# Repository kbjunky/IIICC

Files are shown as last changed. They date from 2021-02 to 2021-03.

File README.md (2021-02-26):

# IIICC
### Three piece split keyboard with macropad running QMK
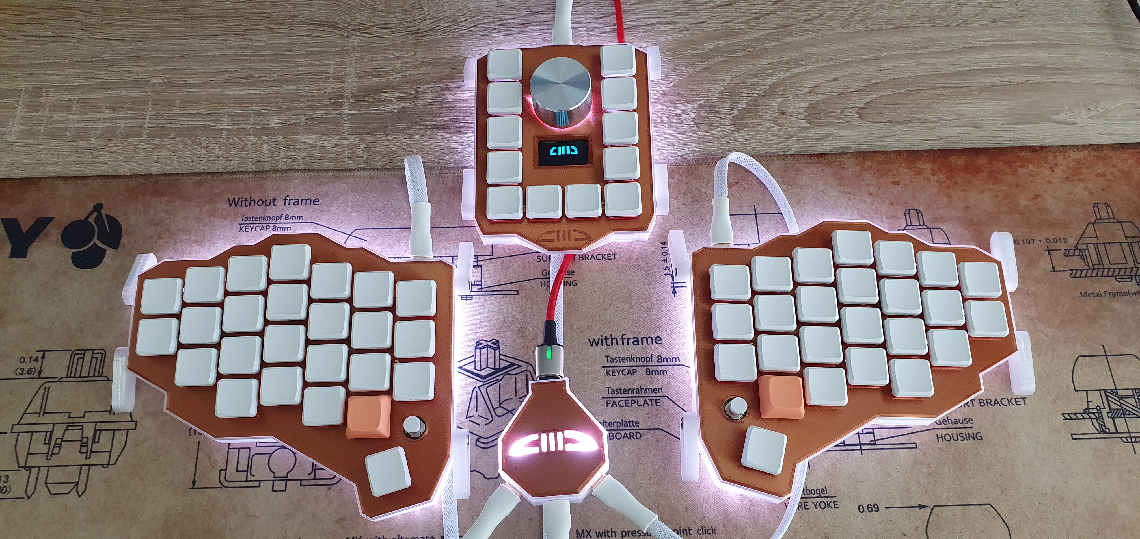
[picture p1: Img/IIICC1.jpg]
IIIC1

Features
- Split ergo
- Additional optional macropad with OLED and rotary encoder
- Central Hub design with only one controller to flash
- 5 way switch on each half for additonal functionality 
- Support for tenting (Ergodox feet should fit), rubber/aluminum feet, 3D printed (included)
- RGB underglow
- 3D printed case and plates
- Support for Kailh Choc V1, Choc V2 and X-Switch(laptop scissor) 
- QMK firmware
- All USB-C connectors
- 'Hexa' case designed by [Sean Yin](https://www.coroflot.com/sean_yin)

[Assembly manual](Doc/IIICC_Assembly_Guide.pdf)

[IIICC PCB & Ordering @ EasyEDA](https://easyeda.com/pigboard)

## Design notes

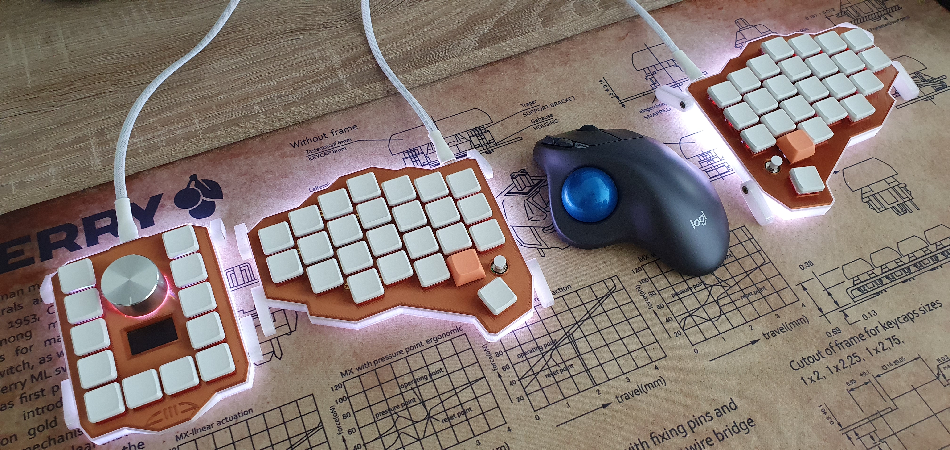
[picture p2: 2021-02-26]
Img/IIICC2.jpg

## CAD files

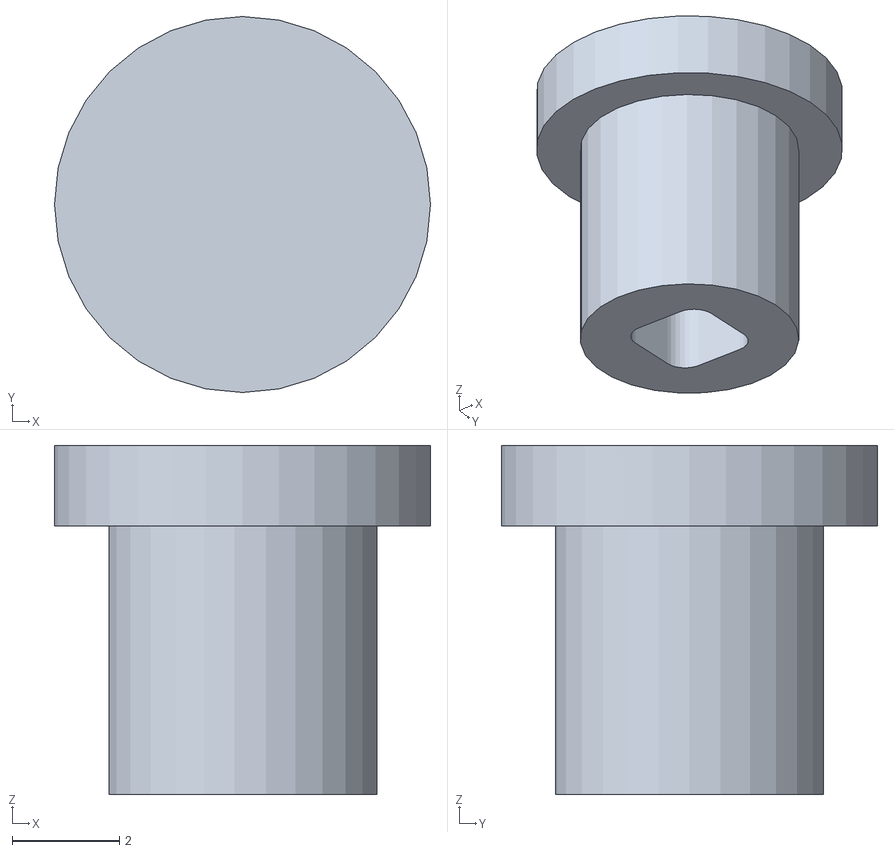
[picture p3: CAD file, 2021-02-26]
Case/3DP/5W_Switch_Cap/5WSwitchCap.stl
7.00 x 7.00 x 6.50

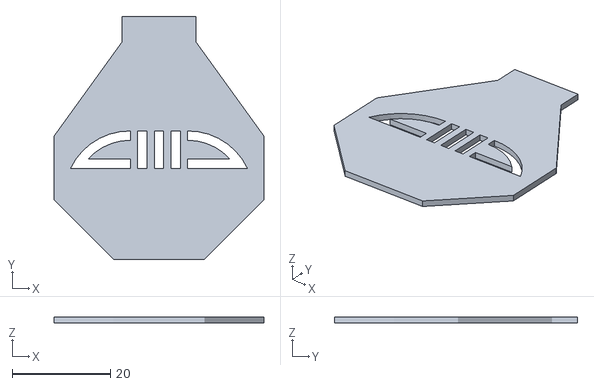
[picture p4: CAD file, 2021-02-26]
Case/3DP/Hub/Hub-Lid_Top.stl
42.6 x 49.4 x 1.20

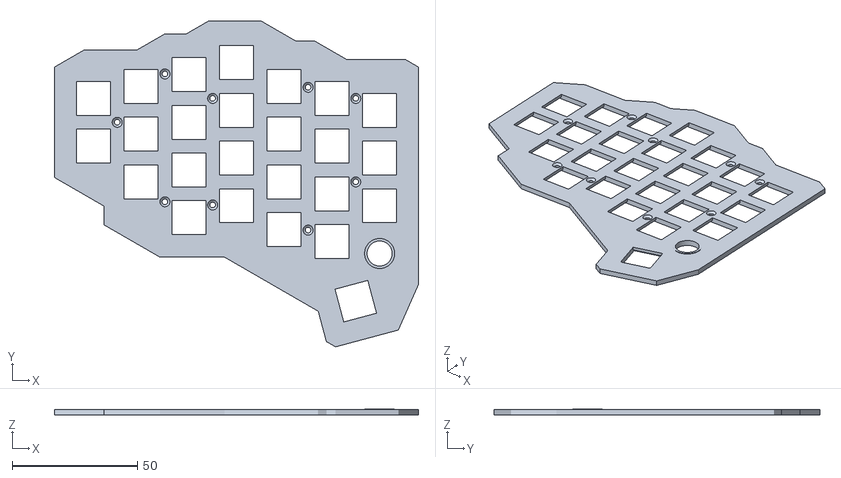
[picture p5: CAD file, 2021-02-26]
Case/3DP/Keyboard/IIICC-Top_Plate_Choc_V1V2.stl
145.3 x 130.1 x 2.40

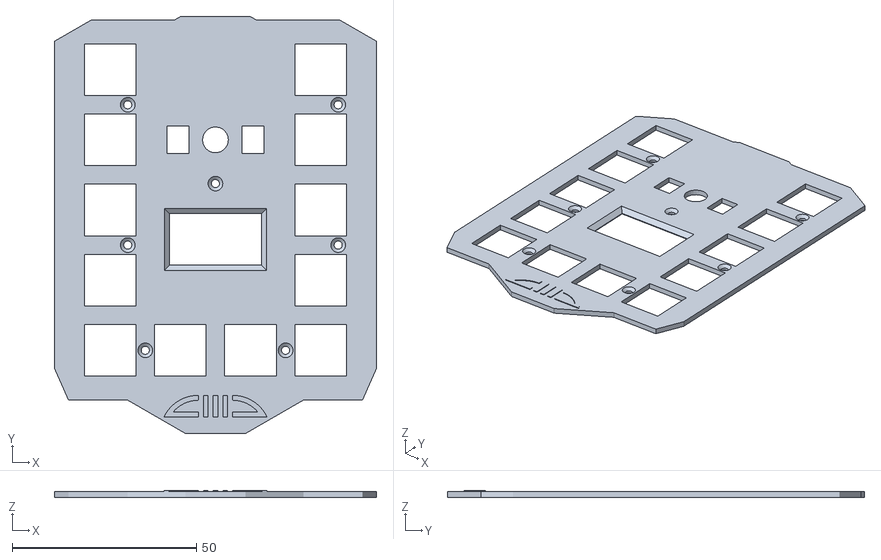
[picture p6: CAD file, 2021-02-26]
Case/3DP/Macropad/Macropad-Top_XSwitch.stl
87.6 x 113.2 x 1.80

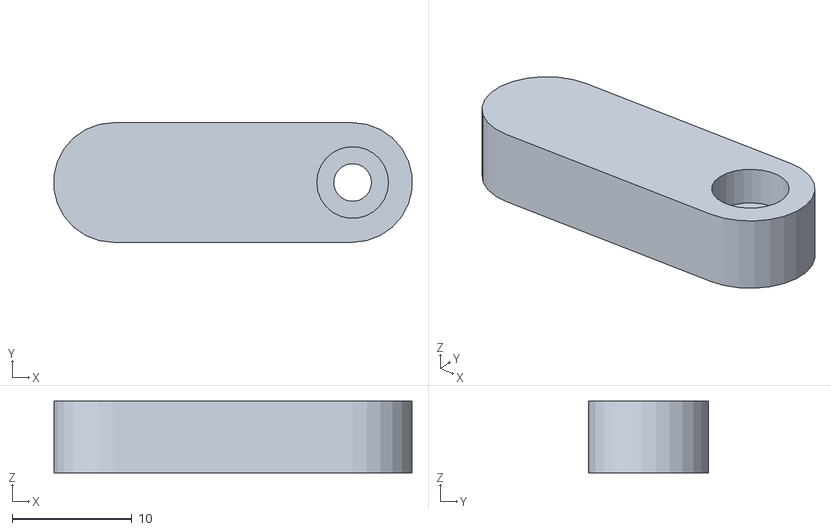
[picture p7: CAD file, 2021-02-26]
Case/3DP/Tenting_Feet/Feet-20mm.stl
29.9 x 10.0 x 6.00

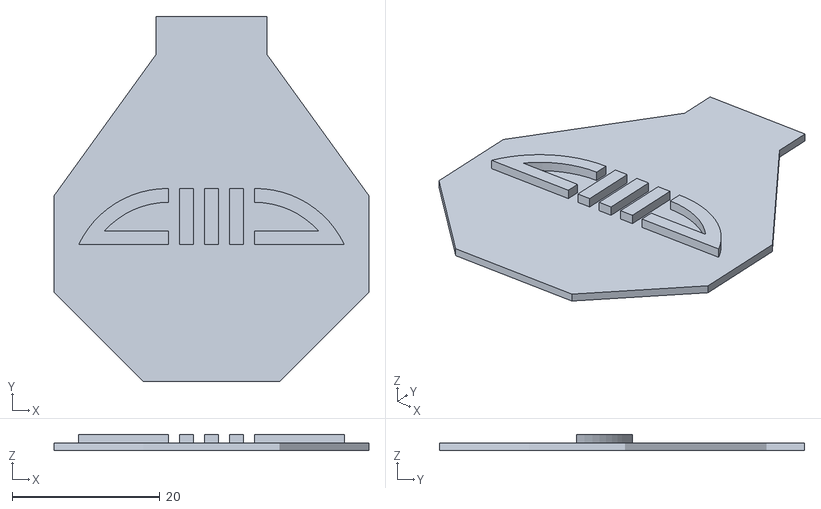
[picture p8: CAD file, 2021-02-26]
Case/3DP/Hub/Hub-Lid_Bottom.stl
42.6 x 49.4 x 2.20

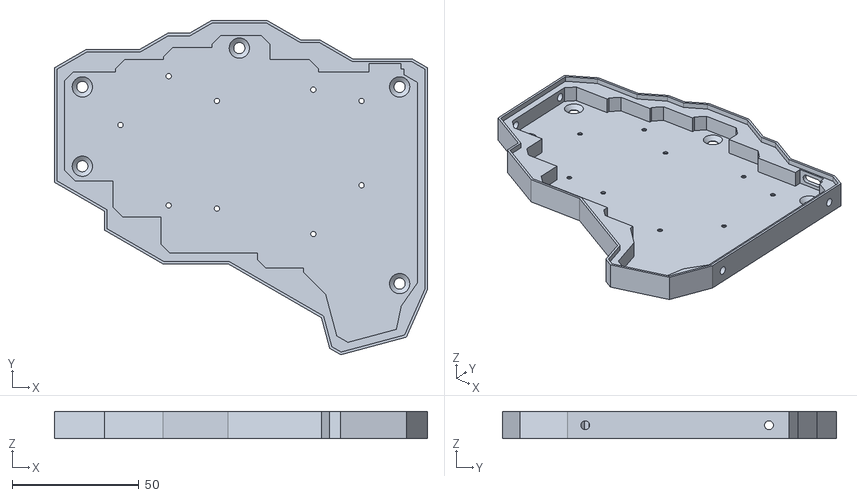
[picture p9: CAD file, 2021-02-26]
Case/3DP/Keyboard/IIICC-Bottom.stl
147.4 x 132.1 x 10.8

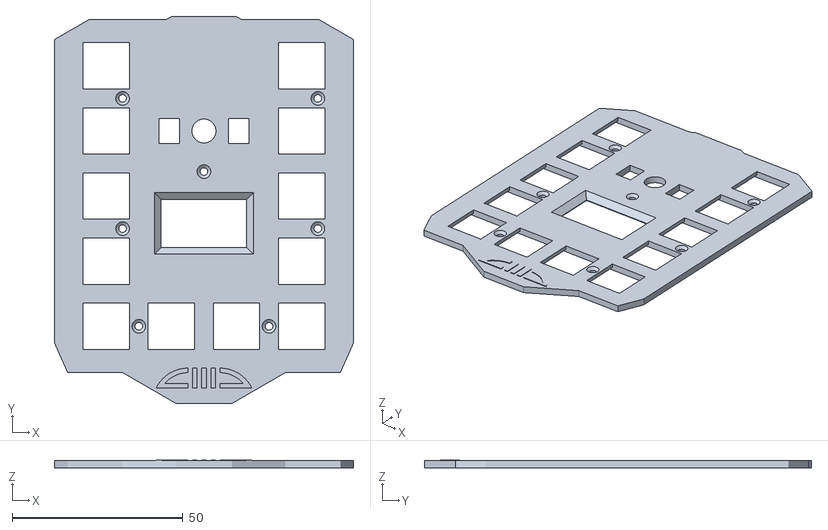
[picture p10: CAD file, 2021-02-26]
Case/3DP/Macropad/Macropad-Top_Plate_ChocV1V2.stl
87.6 x 113.2 x 2.40

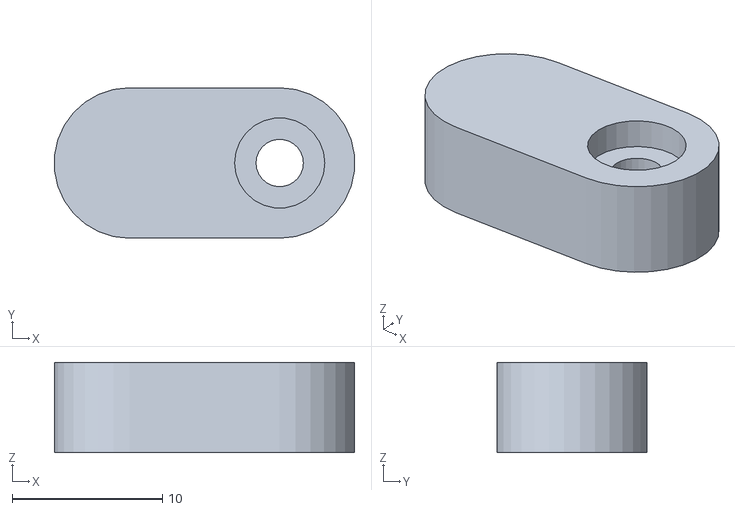
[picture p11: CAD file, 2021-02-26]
Case/3DP/Tenting_Feet/Feet-10mm.stl
19.9 x 10.0 x 6.00

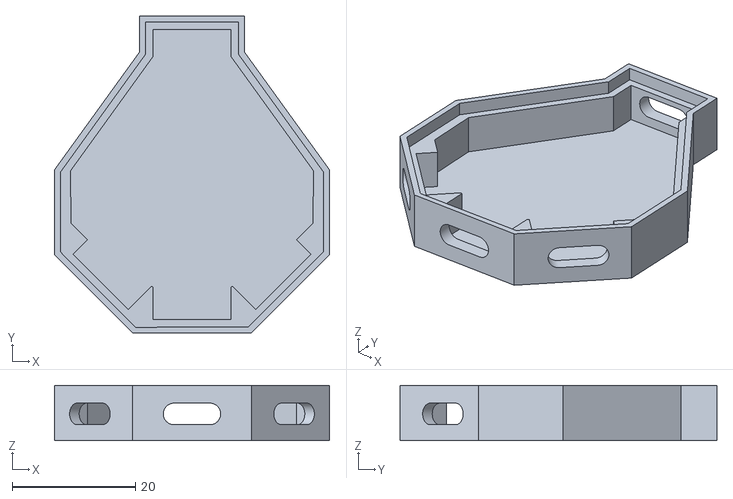
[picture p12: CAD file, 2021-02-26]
Case/3DP/Hub/Hub-Bottom.stl
44.6 x 51.4 x 9.00

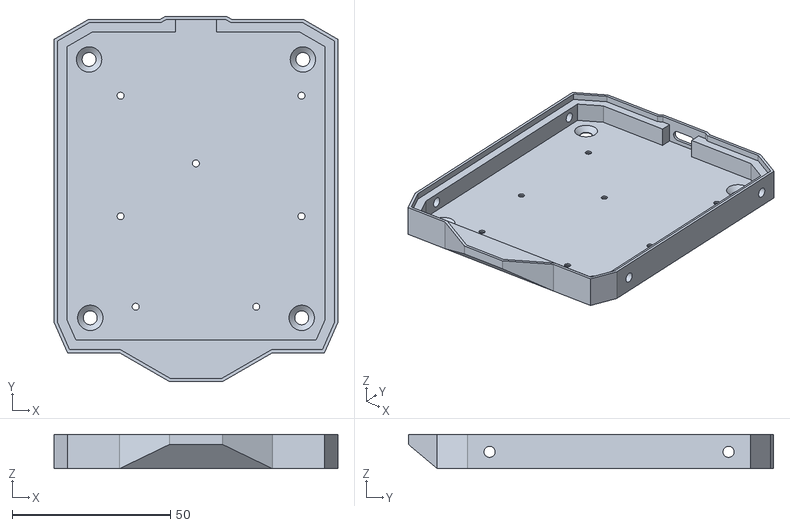
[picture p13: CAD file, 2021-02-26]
Case/3DP/Macropad/Macropad-Bottom.stl
89.7 x 115.3 x 10.8

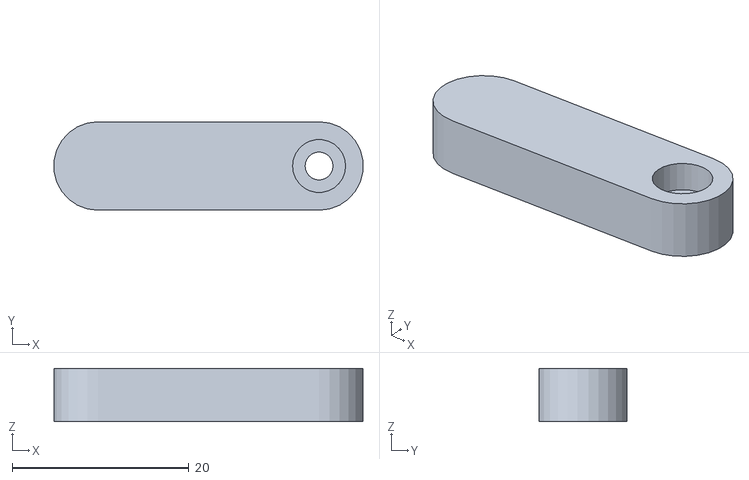
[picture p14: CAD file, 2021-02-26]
Case/3DP/Tenting_Feet/Feet-25mm.stl
34.9 x 10.0 x 6.00

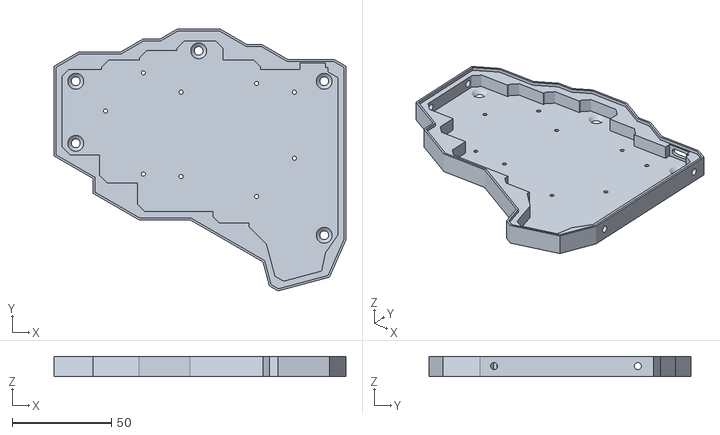
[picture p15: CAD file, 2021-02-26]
Case/3DP/Keyboard/IIICC-Bottom_XSwitch.stl
147.4 x 132.1 x 10.2

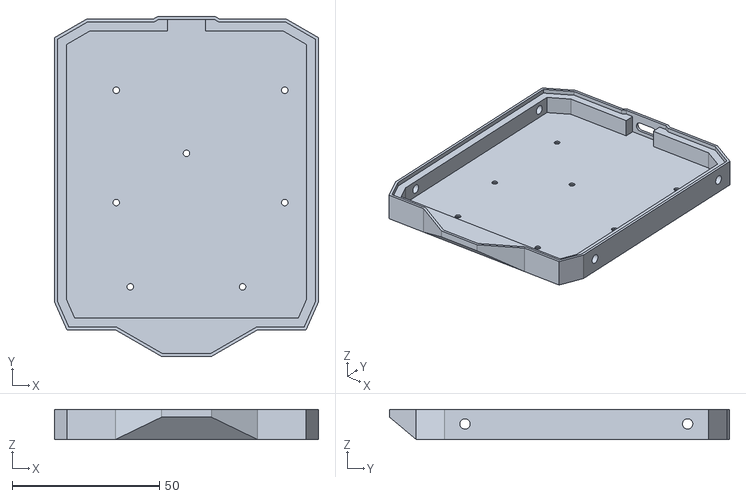
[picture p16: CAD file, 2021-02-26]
Case/3DP/Macropad/Macropad-Bottom_No_Feet_XSwitch.stl
89.7 x 115.3 x 10.2

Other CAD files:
Case/3DP/Keyboard/IIICC-Bottom_No_Feet.stl
Case/3DP/Keyboard/IIICC-Bottom_No_Feet_XSwitch.stl
Case/3DP/Macropad/Macropad-Bottom_XSwitch.stl
Case/3DP/Keyboard/IIICC-Top_XSwitch.stl
Case/3DP/Macropad/Macropad-Bottom_No_Feet.stl

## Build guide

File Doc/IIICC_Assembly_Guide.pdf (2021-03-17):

IIICC by kbjunky (https://www.reddit.com/user/kbjunky) & Sean Yin (https://www.coroflot.com/sean_yin)

### 3 piece split keyboard

Assembly Guide

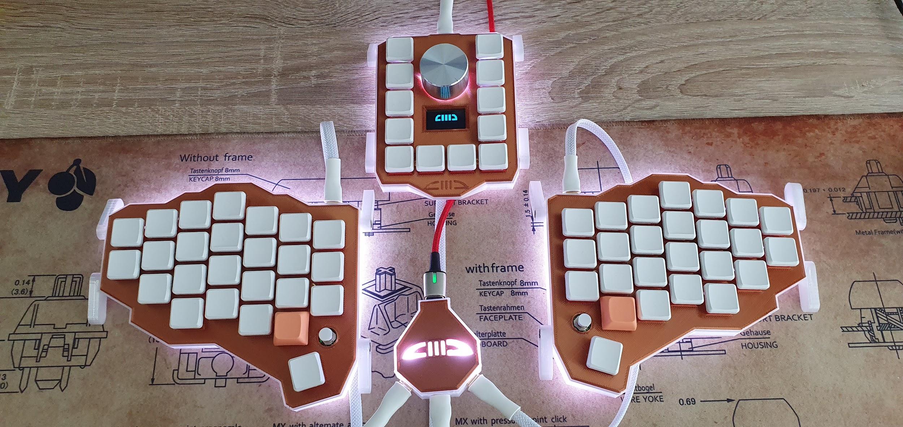
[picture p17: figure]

Bill of materials
Item | Size | Count
22 Ohm | R0805 | 2
330 Ohm | R0805 | 1
1.5k Ohm | R0805 | 1
100nF | C0805 | 51
10k Ohm | R0805 | 2
10uF | C0805 | 1
Oscillator 16MHz | OSC-SMD_4P-L3.2-W2.5-BL | 1
1k Ohm | R0805 | 3
1N4148W T4 | SOD-123_L2.8-W1.8-LS3.7-R D | 75
1uF | C0805 | 1
22pF | C0805 | 2
3.3k Ohm | R0805 | 1
4.7k Ohm | R0805 | 3
4.7uF | C0805 | 1
5.1k Ohm | R0805 | 2
Atmega32U4-AU | QFP-44_L10.0-W10.0-P0.80-LS13.2-BL | 1
USB-C (https://www.aliexpress.com/item/4000259156096.html?spm=a2g0s.9042311.0.0.27424c4d5Fyja3) | | 7
MCP23018-E/SS | SSOP-24_L8.1-W5.3-P0.65-L S7.8-BL | 3
Encoder (https://sg.rs-online.com/web/p/mechanical-rotary-encoders/7377742/) | SW-TH_PEC11R-4220F-S001 2 | 1
Reset button | SW-SMD_L4.0-W2.9-LS5.0 | 1
5W Switch | SW-SMD_TSW-10-1-11B-T15 | 2
WS2812B-B | | 44
OLED 128x64 | | 1
Kailh Choc Hot Swap Socket (https://www.aliexpress.com/item/33023283633.html?spm=2114.12010612.8148356.47.2c2c7aebR0yRfH) | | 50/62
Switches Choc V1/V2/X-Switch | | 50/62
Keycaps | | 50/62
M2 brass flat head screw (https://www.aliexpress.com/item/32792555301.html?spm=a2g0s.9042311.0.0.27424c4dklPrzY) | 6mm | 25
M2 brass flat head screw | 3mm | 25
M2 brass heat insert (https://www.aliexpress.com/item/33021847966.html?spm=a2g0s.9042311.0.0.27424c4dKZ5yBq) | 5mm | 25
M3 hex socket screw (https://www.aliexpress.com/item/4000142028043.html?spm=2114.12010612.8148356.3.2ffa4f9avSfkV5) | 8mm | 12
M3 Thumb screw (https://www.aliexpress.com/item/4000838593040.html?spm=a2g0s.9042311.0.0.27424c4dJjg4a6) | 8mm | 12
Adhesive rubber feet (https://www.aliexpress.com/item/32514500567.html?spm=2114.12010615.8148356.3.3b54498dIeNpzB) | 8x2mm | 20
Double sided adhesive tape (https://www.aliexpress.com/item/4000112107339.html?spm=a2g0s.9042311.0.0.27424c4dF2PZZv)
Aluminum Feet (https://www.aliexpress.com/item/4000643228244.html?spm=a2g0s.9042311.0.0.27424c4de4gp5l) | | 14
Interconnect USB-C Cable (https://www.aliexpress.com/item/4001186462883.html?spm=2114.12010615.8148356.1.729f43ebnEV6Sc) | 0.5m | 3
Magnetic USB-C Hub<->PC Cable (https://www.aliexpress.com/item/4000587078878.html?spm=2114.12010615.8148356.1.9898166ckRijmm) | | 1
Encoder Knob (https://www.aliexpress.com/item/4000317755965.html?spm=a2g0s.9042311.0.0.27424c4dtww8v0) | 30x17mm | 1

About keycap compatibility

All Choc V1 caps should fit including MBK. Good idea is to put XDA on Space and Enter while using Choc V1. This gives a bit more flexibility while pressing those keys (easier to reach with a thumb).

For Choc V2 I have tested only two types:
YMDK XDA (https://www.aliexpress.com/item/32864098498.html?spm=a2g0s.9042311.0.0.27424c4dmsWMkX) - OK

YMDK ABS OEM(?) profile (https://www.aliexpress.com/item/32834702181.html?spm=a2g0s.9042311.0.0.27424c4djNetZY) - for this only buy R1 to R3 and use reversed R1 on row 4 (bottom row). R4 keycaps from this store won’t hold, seems like they are too high (more like switch/stem being too short).
In terms of keycaps hitting the plate on Choc V2 I have not noticed any problem with that. Seems like there’s still tiny space left.

For Kailh X-Switch there are no other keycaps than the one Kailh is selling on their store. Link. (https://www.aliexpress.com/item/32987116768.html?spm=2114.12010612.8148356.23.100836a4Enr8On)

About LEDs and USB-C

I have made available pads for VCC/GND/D+/D-/LED_DATA on the PCB. A USB-C pinout board can be used but most probably it won’t fit the case. Maybe in the future I will add a slightly angled case so this might come handy. As for LEDs a WS2812 strip can be used instead of soldering all the capacitors and LEDs.

PCB Ordering

PCBs were created using EasyEDA and can be directly ordered from there. Use default settings when making your order, that is:
Layers: 2
PCB Qty: 5 (min) or more depending on your needs
Delivery format: Single PCB
PCB Thickness: 1.6mm
PCB Color: Green (default) but you can choose any other color available Surface Finish: HASL(with lead)
Copper Weight: 1 oz
Gold fingers: No
Confirm production file: No Flying probe Test: Fully Test
Castellated Holes: No
Remove Order Number: No

Each part has to be ordered separately. Left, Right and Hub are mandatory. Macropad is optional.

Tools

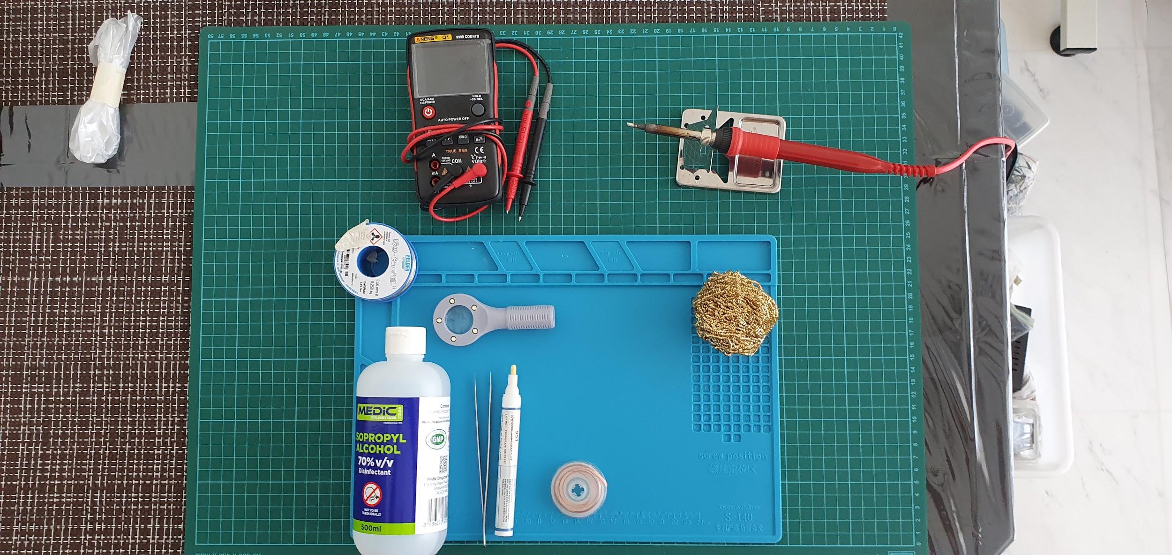
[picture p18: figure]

Minimum set of tools/materials required for this build: Soldering iron. (https://www.aliexpress.com/item/1005001343006528.html)
0.5mm Lead Solder. (https://sg.rs-online.com/web/p/solder/1796656/)
No clean flux. Marker (https://www.aliexpress.com/item/33004145488.html) or syringe. (https://www.aliexpress.com/item/32788246494.html)
Multimeter (https://www.aliexpress.com/item/1005001693526242.html) with diode test.
Tweezers (https://www.aliexpress.com/item/32819516775.html) for SMD elements.
Isopropyl alcohol for cleaning PCBs. (Got mine at a pharmacy store)
Magnifying (https://www.aliexpress.com/item/4001275940469.html) glass might come handy especially if it’s on an arm. Or anything to help with soldering USB-C ports and ICs.
Hot glue gun (https://www.aliexpress.com/item/1005001393578323.html) to secure USB-C ports to the PCB
Desoldering wick (https://www.aliexpress.com/item/32958719300.html) for cleaning of solder when things go wrong.
Brass sponge (https://www.aliexpress.com/item/32964436795.html) for cleaning the tip.

Assembly

You should start with the Hub. First solder in USB-C port that connects Hub to the PC. Check for shorts using pads on the PCB.
D+ <-> D-GND <-> Vcc
VCC <-> CC1 (5.1k resistor pad)
D- <-> CC2 (5.1k resistor pad)

Next solder in the rest of USB ports one at a time checking for shorts on: VCC <-> RGB
VCC <-> GND
SDA <-> SCL
SCL <-> RGB

After this is done you can proceed to installing Atmega and all the elements around it. For now skip LED diodes and 100nF capacitors located between them and the edge of the board. Once done connect the board to the PC. If you see a message about an unrecognized device most probably there’s a short on VCC and or D+/D-. Double check with a multimeter. If all is good you should be able to flash firmware onto it. Follow QMK guide on flashing firmware.
Finish assembly by installing LEDs and accompanying capacitors. Connect again to check if LEDs are working fine. Be sure to have Macropad disabled for the testing phase as without an OLED screen present driver might freeze the controller.

Next assemble either the left or right keyboard part. Leave the macropad last. Steps below apply to all of the parts.
Just like with the Hub first thing that needs to be installed is the USB-C port. Check for shorts using pads on the PCB.
SCL <-> SDA
RGB <-> SCL
Vcc <-> RGB
Vcc <-> GND

After that install I2C expander (MCP23018) and: Right:
4.7k address resistor
1k Reset pull-up resistor
100nF Vcc capacitor

Left:
1k Reset pull-up resistor
100nF Vcc capacitor

Macropad:
1.5k and 3.3k address resistors 1k Reset pull-up resistor
100nF Vcc capacitor

After MCP23018 is installed you should check for shorts on:
Vcc <-> SCL
SCL <-> SDA

At this point it’s good to check if communication is working. Install one diode to the nearest switch to the USB-C port. Connect this part to the Hub and use https://keycode.info/ to check if keypress is reported. If not check again for any shorts on the I2C line as well as Vcc/GND. If it works the rest is easy but a bit time consuming. Install all switching diodes, check each key if it works. Then you can proceed to LEDs + capacitors. Best way to install LEDs is in small steps. One or two diodes at a time and check if they work. After that install hot swap sockets. Last but not least, the 5W switch. It doesn’t like high temperatures for too long as well as too much solder. Install it as the last element and don’t use too much solder/heat. Otherwise it might stop being ‘tactile’.

Special note on macropad.
Two things require special steps: an OLED screen and a rotary encoder. OLED should fit inside the cutout. Place it there and use hot glue to glue it to the pcb. Then use a wire to connect OLED to the VCC, GND, SDA, SCL pads nearby.

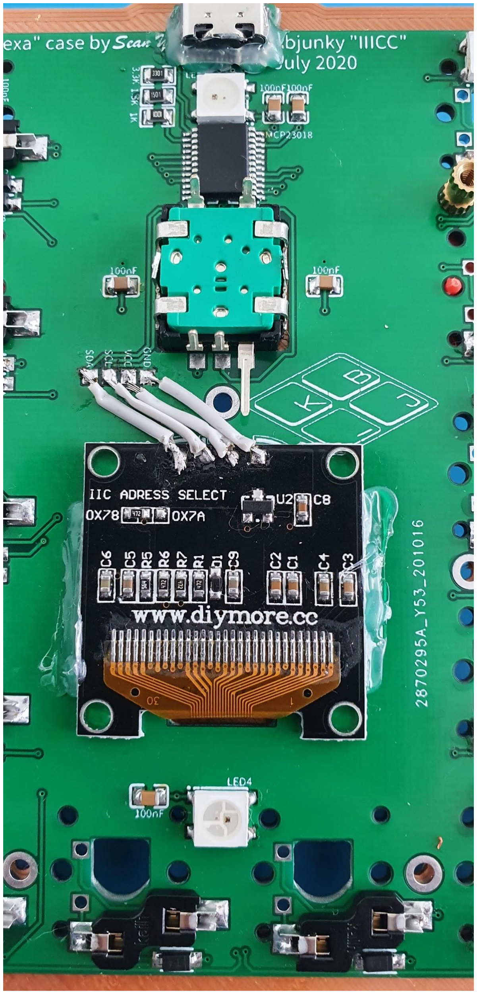
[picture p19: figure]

If your OLED doesn’t work you can try changing its address in firmware. Oddly enough the one I have used while building had the same address as 128x32 which is 3C. 128x64 usually has an address of 0x7C or 0x78 (it’s at the back of the screen).

As for the encoder it’s best to have the top plate printed. Push it through the hole in the plate and tighten with the screw. Now attach the plate to the PCB so that it won't be moving (2 screws will do). Cut off the GND pins (the thick ones on the sides) we won’t be needing them. Position the rotary encoder so that pins align with pads on the pcb (3 bottom ones and 2 on top). Now bend the pins towards the PCB and trim them so that they are touching the PCB. Solder them to the pads and put the washer and the nut that came with the encoder on the top part of the plate to secure it further.

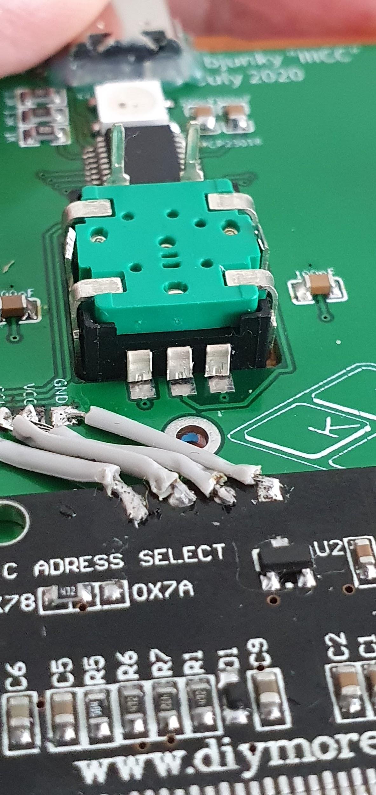
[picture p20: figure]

Case assembly

At this point you should have all the pieces working so it’s a good time to use hot glue on USB-C ports to secure them to the PCB.
Choose Choc V1/V2 or X-Switch compatible parts. It’s possible to print Choc V1/V2 compatible bottom case and use it with an X-Switch plate. Only difference is that the outline of the case will be slightly higher than the plate. It’s because the plate for Choc is 2.2mm and for X-Switch 1.6. Also decide if you need support for bottom rubber feet or not (additional M4 holes on the bottom). After printing is done assembly is rather easy. Install heated inserts on the sides. Attach PCB to the top plate with a 6mm flat head screw (from the top). Heated inserts will also be used as spacers on the bottom side of the PCB where the top plate mounting screws are. Once this is done put two pieces together. Top plate should click in. From the bottom screw in 3mm flat head screws to secure top plate and bottom case together.
Hub doesn’t need any screws. All parts should fit in tight. Insert PCB into bottom case. First insert USB-C to PC port. Then slide it back a bit so that all the ports align. Then the top plate is two pieces. Transparent bottom one with extruded IIICC logo should fit with the top one in a way that extruded letters go through IIICC cutout in the top part.

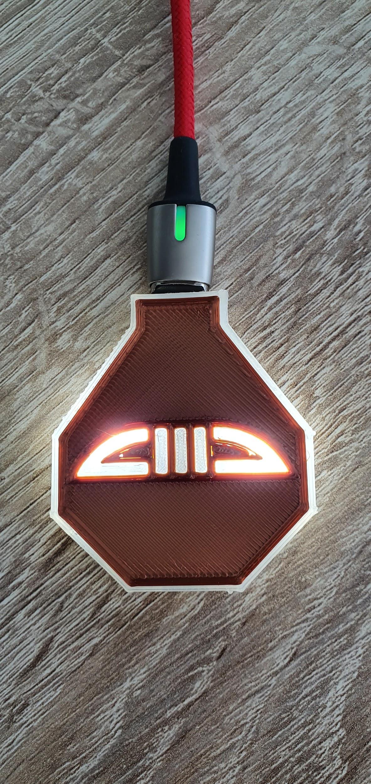
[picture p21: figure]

Tenting feet

You can choose between 25mm, 20mm and 10mm so it’s more of a trial and error before you find the most suitable ones. Use double sided adhesive tape to prevent the keyboard from sliding while tented.

Printing

Top plates printed with shiny copper PLA Layer height 0.2
Infill 100%

Bottom cases printed with translucent PLA
Layer height 0.2
Infill 30%
Support ON (unless your printer can print USB-C cutout without it)

Feet
Layer height 0.2
Infill 30%

5W Switch cap
Layer height 0.2
Infill 100%

Layout

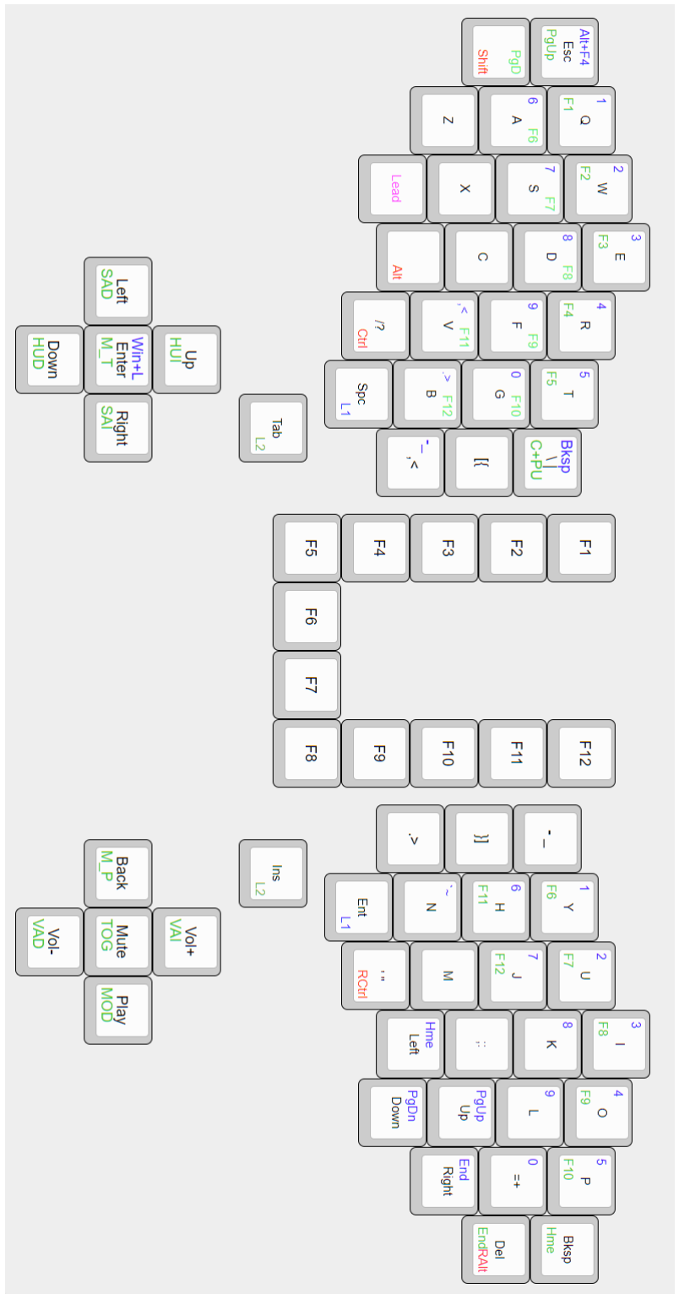
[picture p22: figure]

Leader key combinations:

+ W - Win
+ B - Reset/Programming
+ W,R - Command
+ W,L - Logout
+ W,S - Screenshot
+ W,T - Win+Tab (cycle Windows) + C,A,D - Ctrl+Alt+Del
+ C,A,E - Ctrl+Alt+End (for RDP) + A - Alt+Shift+Insert (Far Manager) + Q - Ctrl+PgUp (Far Manager)
+ S - Caps Lock

Compilation

Prepare your build environment by following QMK official Getting Started (https://docs.qmk.fm/#/newbs_getting_started) guide. Checkout code from my Github repository at https://github.com/kbjunky/IIICC. Default setup will compile with macropad support thus if it’s not present (especially when OLED is not installed) it might cause some problems.

To enable macropad and OLED:
In rules.mk:
OLED_DRIVER_ENABLE = yes
In config.h:
#define MACROPAD_ENABLE

To disable macropad and OLED:
In rules.mk:
OLED_DRIVER_ENABLE = no
In config.h:
//#define MACROPAD_ENABLE

If you are having issues with the keyboard enable debug mode and check output either in QMK Toolbox or hid_listen.exe. Underglow needs to be disabled while console is enabled otherwise firmware will exceed allowed size:
To enable debug mode:
In rules.mk:
CONSOLE_ENABLE = yes
RGBLIGHT_ENABLE = no

You can also enable/disable boot animation and change it’s interval. In keymap.c:
#define BOOT_ANIM_ENABLED

#define BOOT_ANIM_DELAY 125

Hub can support a matrix of 3 devices of 8 columns and 8 rows each. Can be easily extended by modifying IIICC.h with a new key matrix.

Links

https://easyeda.com/pigboard - my electronics projects including IIICC https://github.com/kbjunky/IIICC - IIICC Github page https://www.coroflot.com/sean_yin - designer of ‘Hexa’ case art page kbjunky#6476 - Discord

Enjoy your IIICC
Thank you!

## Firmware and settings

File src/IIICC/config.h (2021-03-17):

/*
Copyright 2020 kbjunky

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
You should have received a copy of the GNU General Public License
along with this program.  If not, see <http://www.gnu.org/licenses/>.
*/

#pragma once

#include "config_common.h"


/* USB Device descriptor parameter */
#define VENDOR_ID 0xFEED
#define PRODUCT_ID 0x0000
#define DEVICE_VER 0x0001
#define MANUFACTURER kbjunky
#define PRODUCT IIICC
#define DESCRIPTION Three Split keyboard with macropad

/* Macropad */
#define MACROPAD_ENABLE //uncomment to enable macropad

/* OLED settings */
//#define OLED_DISPLAY_ADDRESS 0x78 //128x64 sometimes run on 0x3C just like 128x32, that was the case for me
#define OLED_DISPLAY_128X64
#define OLED_FONT_H "keyboards/IIICC/glcdfont.c"
#define OLED_TIMEOUT 0
//full matrix, we skip macropad scanning in matrix.c if not defined here
#define MATRIX_ROWS 5
#define MATRIX_COLS 20

/* COL2ROW, ROW2COL*/
#define DIODE_DIRECTION COL2ROW

/* Debounce reduces chatter (unintended double-presses) - set 0 if debouncing is not needed */
#define DEBOUNCE 10

#define NO_ACTION_MACRO
#define NO_ACTION_FUNCTION

/* Leader key */
#define LEADER_TIMEOUT 450
#define LEADER_PER_KEY_TIMING

/* Tapping timout */
#define TAP_CODE_DELAY 20
#define TAPPING_TERM 200
#define PERMISSIVE_HOLD
#define IGNORE_MOD_TAP_INTERRUPT

/* RGB Light */
#define RGB_DI_PIN F4
#ifdef RGB_DI_PIN
   #define RGBLED_NUM 16
   #define RGBLIGHT_HUE_STEP 10
   #define RGBLIGHT_SAT_STEP 15
   #define RGBLIGHT_VAL_STEP 15
   #define RGBLIGHT_LIMIT_VAL 255 /* The maximum brightness level */
   #define RGBLIGHT_SLEEP  /* If defined, the RGB lighting will be switched off when the host goes to sleep */
 /*== all animations enable ==*/
   #define RGBLIGHT_ANIMATIONS
 /*== or choose animations ==*/
//    #define RGBLIGHT_EFFECT_BREATHING
//    #define RGBLIGHT_EFFECT_RAINBOW_MOOD
//    #define RGBLIGHT_EFFECT_RAINBOW_SWIRL
//    #define RGBLIGHT_EFFECT_SNAKE
//    #define RGBLIGHT_EFFECT_KNIGHT
//    #define RGBLIGHT_EFFECT_CHRISTMAS
//    #define RGBLIGHT_EFFECT_STATIC_GRADIENT
//    #define RGBLIGHT_EFFECT_RGB_TEST
//    #define RGBLIGHT_EFFECT_ALTERNATING
// /*== customize breathing effect ==*/
//   /*==== (DEFAULT) use fixed table instead of exp() and sin() ====*/
//   #define RGBLIGHT_BREATHE_TABLE_SIZE 256      // 256(default) or 128 or 64
//   /*==== use exp() and sin() ====*/
//   #define RGBLIGHT_EFFECT_BREATHE_CENTER 1.85  // 1 to 2.7
//   #define RGBLIGHT_EFFECT_BREATHE_MAX    255   // 0 to 255
 #endif

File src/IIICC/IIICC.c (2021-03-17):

/* Copyright 2020 kbjunky
 *
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
 * You should have received a copy of the GNU General Public License
 * along with this program.  If not, see <http://www.gnu.org/licenses/>.
 */

#include "IIICC.h"

#define HIGH 0b11111111
#define LOW 0

static i2c_status_t last_err = 0;
bool i2c_initialized = false;

void i2c_initialize(void){
    dprint("I2C init start\n");
     
    if(!i2c_initialized) {
        i2c_init();
        i2c_initialized = true;
        
    }

    //1st device
    //set A as outputs
    i2c_write8(I2CA_ADDRESS, IODIRA, LOW);
    //seems like A pull ups also needed
    i2c_write8(I2CA_ADDRESS, GPPUA, HIGH);
    //set B pull ups ON
    i2c_write8(I2CA_ADDRESS, GPPUB, HIGH);

    if(i2c_last_error()) {
        dprint("Unable to setup right side!\n");
    }else {
        dprint("Right side OK!\n");
    } 
    
    //2nd device
    i2c_write8(I2CB_ADDRESS, IODIRA, LOW);
    //seems like A pull ups also needed
    i2c_write8(I2CB_ADDRESS, GPPUA, HIGH);
    //set B pull ups ON
    i2c_write8(I2CB_ADDRESS, GPPUB, HIGH);
    if(i2c_last_error()) {
        dprint("Unable to setup left side!\n");
    }else {
        dprint("Left side OK!\n");
    }  

#ifdef MACROPAD_ENABLE
    //3rd device - macropad
    i2c_write8(I2CM_ADDRESS, IODIRA, LOW);
    //seems like A pull ups also needed
    i2c_write8(I2CM_ADDRESS, GPPUA, HIGH);
    //set B pull ups ON
    i2c_write8(I2CM_ADDRESS, GPPUB, HIGH);
    if(i2c_last_error()) {
        dprint("Unable to setup macropad!\n");
    }else {
        dprint("Macropad OK!\n");
    }  
#endif
    
}

bool isI2C_initialized() {
    return i2c_initialized;
}

uint8_t i2c_read8(uint8_t addr, uint8_t reg) {
    uint8_t data = 0;
    last_err = i2c_start(addr, I2C_TIMEOUT); if(last_err) goto end;
    last_err = i2c_readReg(addr, reg, &data, sizeof(data), I2C_TIMEOUT); if(last_err) goto end;    
    end:
        i2c_stop();
    return ~data;

}

void i2c_write8(uint8_t addr, uint8_t reg, uint8_t data) {
    last_err = i2c_start(addr, I2C_TIMEOUT); if(last_err) goto end;
    last_err = i2c_writeReg(addr, reg, &data, sizeof(data), I2C_TIMEOUT); if(last_err) goto end;
    end:
        i2c_stop();
}

void i2c_select_row(uint8_t row_index) {
    uint8_t row_mask = ~(1 << row_index);
    i2c_write8(I2CA_ADDRESS, GPIOA, row_mask);
}

void i2c_select_row_on(uint8_t addr, uint8_t row_index) {
    uint8_t row_mask = ~(1 << row_index);
    i2c_write8(addr, GPIOA, row_mask);
} 

i2c_status_t i2c_last_error(void) {
    return last_err;
}

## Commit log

2021-02-26 Fixed units in BOM
2021-03-17 Minor modifications
    Removed hex files
    Updated guide - compilation hints
    Changes to matrix/I2C scanning
    Added boot animation flag/interval
2021-07-20 Encoder fixes

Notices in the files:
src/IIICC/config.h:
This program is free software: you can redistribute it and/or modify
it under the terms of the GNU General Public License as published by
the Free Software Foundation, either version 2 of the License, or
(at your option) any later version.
